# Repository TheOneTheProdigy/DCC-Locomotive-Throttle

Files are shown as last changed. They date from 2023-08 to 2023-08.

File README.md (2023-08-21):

# DCC-Locomotive-Throttle

The DCC-Locomotive-Throttle is a simple DIY, handheld controller that talks to a wThrottle Server (JMRI, DCC++EX and many others) using the wiThrottle protocol to control DCC model trains. 

---

## Prerequisites

1. Some basic soldering skills.  

    The components will work if just plugged together using jumpers, but they take a lot of space that way, so soldering them together is advised to make it hand held.

2. Loading the code (sketch) requires downloading of one of the IDEs, this sketch, the libraries, etc. so some experience with Arduinos is helpful, but not critical.

3. A wiThrottle Server to connect to. DCC-Locomotive-Throttle will work with any wiThrottle Server. e.g.

    * JMRI
    * DCC++EX
    * MRC WiFi
    * Dijitrax LnWi

---

## Building

Required Components

* ESP32 Lite Type C With Onboard Battery Circuit.
* 3x4 Keypad Matrix
* Polymer Lithium Ion Battery LiPo Maker Focus 2000mAh 3.7V JST Connector. On Battery BMS is a must for safety.
* KS0013  Rotary Encoder Module
* OLED Display 1.3" 128x64 I2C IIC SSD1306
* Case - 3D Printed
* Knob 3D Printed
* Wire - If you plan to solder the connections,which is the recommended approach, then stranded, coloured wire is advisable.
* Optional: Up to 7 additional buttons can be added, each with their own independent commands.

*Standard Configuration Pinouts*
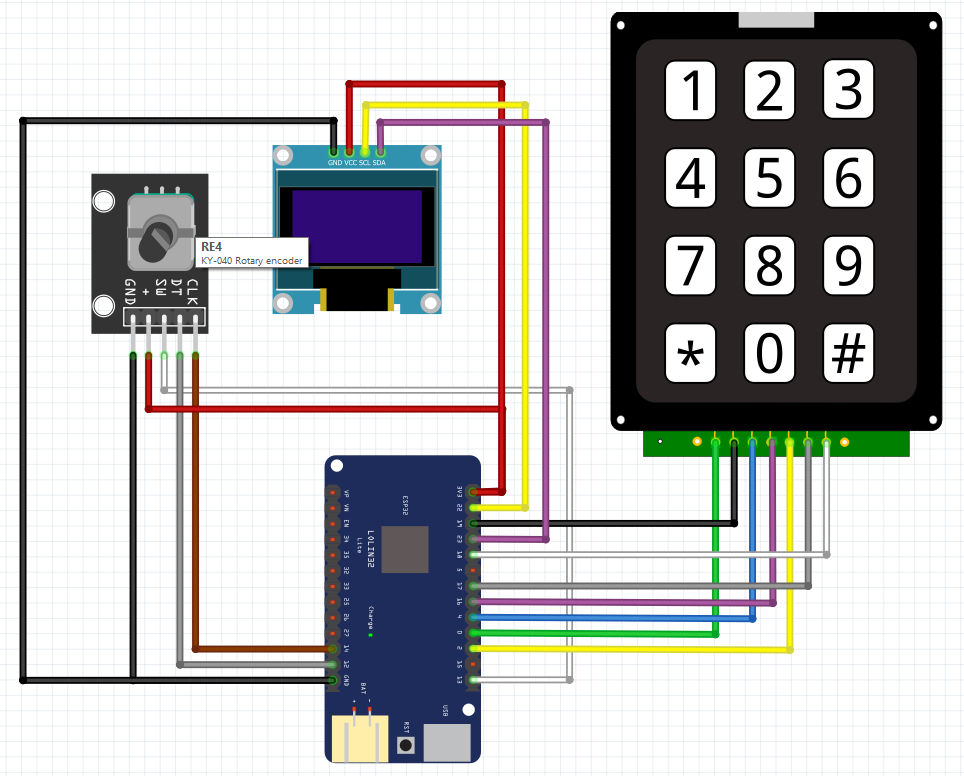
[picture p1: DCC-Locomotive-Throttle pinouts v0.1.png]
Assembly diagram


*Pinouts for Optional Additional Buttons*
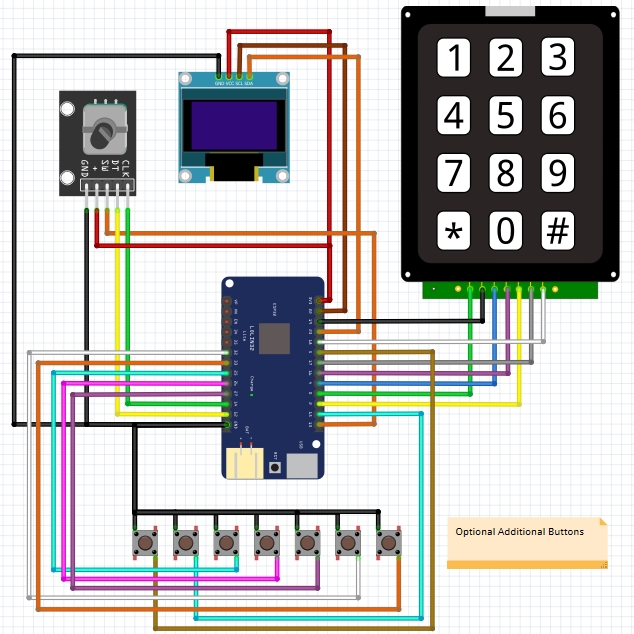
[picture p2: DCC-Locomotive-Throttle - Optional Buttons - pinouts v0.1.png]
Assembly diagram - Optional Additional Buttons


## Loading the code

1. Download the Arduino IDE.  
    * Available from  https://support.arduino.cc/hc/en-us/articles/360019833020-Download-and-install-Arduino-IDE
2. Download the esp32 boards in the Arduino IDE.
    * add the esp322 support with the following instructions:  (See here for detailed instructions:  https://randomnerdtutorials.com/installing-the-esp32-board-in-arduino-ide-windows-instructions/)
        * In the Arduino IDE, go to *File* > *Preferences*
        * Enter the following into the 'Additional Board Manager URLs' field:  https://dl.espressif.com/dl/package_esp32_index.json
    * Then Use the *Boards Manager* in the *Arduino IDE* to install the esp32 board support
        * *Tools* > *Board* > *Boards Manager*
        * Search for "esp32" by Expressive Systems.  Install version 1.0.6
3. Download or clone *this* repository. (Note: if you 'clone' initially, it is easier to receive updates to the code by doing a 'fetch' subsequently.  See Notes below.)
    * Clone - **First Time**
       * Install *GitHub Desktop* from https://desktop.github.com/
       * Create a free account on GitHub and authorise the app to allow it to connect top GitHub
       * Select *file* -> *Clone Repository* - or 'Clone an repository from the internet' from the welcome page then select the 'URL' tab
       * Enter *https://github.com/TheOneTheProdigy/DCC-Locomotive-Throttle* as the URL
       * Select a local folder to install it.  The default folder for the Arduino usually looks like "...username\Documents\Arduino\". (This is a good but not essential place to put it.)
       * Click *Clone*
       * **Subsequently**  (Anytime after the first 'clone')
         * click *Fetch Origin* and any changes to the code will be bought down to you PC, but you config_buttons.h and config_network.h will not be touched.
    * Download 
       * Open *https://github.com/TheOneTheProdigy/DCC-Locomotive-Throttle*
       * Click the green "Code" button and select download zip
       * Extract the zip file to a local folder.  The default folder for the Arduino usually looks like "...username\Documents\Arduino\". This is a good but not essential place to put it.
4. Load the needed libraries to your PC. These can loaded from the *Library Manager* in the *Arduino IDE*.
    * *U8g2lib.h* -  Search for "U8g2"   Install version 2.34.22
    * *AiEsp32RotaryEncoder.h* - search for "Ai Esp32 Rotary Encoder"  Install Version 1.6
    * *Keypad.h* - Search for "Keypad" by Mark Stanley   install version 3.1.1
    * *WiThrottleProtocol.h* - Search for "WiThrottleProtocol" (not "WiThrottle")  Install version 1.0.3 or later if available
5. These should have been automatically installed when you downloaded the esp32 boards.
    * *WiFi.h*  - https://github.com/espressif/arduino-esp32/tree/master/libraries/WiFi
    * *ESPmDNS.h* - https://github.com/espressif/arduino-esp32/blob/master/libraries/ESPmDNS
6. Copy '**config_network_example.h**' to a new file to '**config_network.h**'.
    * Then edit it to include the network ssids you want to use.  (Not essential, but entering passwords via the encoder is tedious.)
7. Copy '**config_buttons_example.h**' to a new file '**config_buttons.h**'.
    * Optionally, edit this to change the mapping of the keypad buttons to specific functions.
    * Optionally, edit this to configure the additional buttons (if you have included them) to specific functions.
    * Optionally, edit this to change if you want the function buttons to display when you press #, instead of the default of showing the Key Definitions
8. Upload the sketch.  
    * Select the board type as "WEMOS LOLIN32 Lite" in the *Arduino IDE*.
    * Connect the board via USB and select the appropriate port in the *Arduino IDE*.
    * Click *Upload* 

Notes: 
   * DCC-Locomotive-Throttle version 1.19 or later requires WiThrottleProtocol version 1.1.3 or later.
   * DCC-Locomotive-Throttle version 1.06 or later requires WiThrottleProtocol version 1.1.2 or later.
   * DCC-Locomotive-Throttle version 1.01 or later requires WiThrottleProtocol version 1.1.0 or later.
   * DCC-Locomotive-Throttle version 0.10 or later requires WiThrottleProtocol version 1.0.3 or later.
   * The *WiFi.h* and *ESPmDNS.h* libraries were automatically installed for me when I installed the esp32 boards, however you may need to install them manually.
   * Later versions of the esp board support are available and do appear to work, but if you have difficulties version 1.0.6 appears to be stable.
   * Later versions of the libraries generally should work, but if you have difficulties use the versions listed above.
   * To get the DCC-Locomotive-Throttle sketch I recommend using either the git command line, or the far more friendly 'GitHub Desktop' app.  See instructions above.
   * If you receive and error related to Python, and you are on MacOs 12 and above please edit the platform file, change from python to python3 as follows; preferences->user/path/arduino/packages/hardware/esp32/version/platform.txt and edit the line that looks as follows:tools.gen_esp32part.cmd=python3 "{runtime.platform.path}/tools/gen_esp32part.py"

---

## Using DCC-Locomotive-Throttle

**Currently functioning:**
- Provides a list of discovered SSIDs with the ability to choose one. When you select one:
  - if it is one in your specified list (in the sketch), it will use that specified password 
  - if it is a DCC++EX wiFi Command Station in access Point mode, it will guess the password
  - otherwise it will ask to enter the password (Use the rotary encoder to choose each character and the encoder button to select it.  * = backspace.  # = enter the password.) 
- Optionally provides a list of SSIDs with the specified passwords (in the sketch) to choose from
- Auto-connects to the first found wiThrottle Protocol Server if only one found, otherwise 
  - Asks which to connect to
  - If none found will ask to enter the IP Address and Port
  - Guesses the wiThrottle IP address and Port for DCC++EX WiFi Access Point mode Command Stations
  - optionally can add a #define (a preference) to disable this auto connect feature
- Rudimentary on-the-fly consists
- Assign commands directly to the 1-9 buttons (in the sketch) (see list below)
  - This is done in config_button.h
  - Latching / non-latching for the function is provided by the roster entry of wiThrottle server
- Optional ability to assign commands directly to the 1-7 additional buttons (in the sketch) (see list below)
  - These are defined config_button.h
- Command menu (see below for full list) including:
  - Able to select and deselect locos 
    - by their DCC address, via the keypad
      - On NCE systems, a leading zero (0) will force a long address
    - from the first 50 locos in the roster
  - Able to select multiple locos to create a consist
    - Able to change the facing of the additional locos in the consists (via the 'extra' menu after selection)
  - Able to activate any function (0-28)
    - Showing of the roster function labels (from the wiThrottle server if provided)
    - Quick access to the functions by pressing #. Temporarily enabled via the Extras menu (or permanently enabled in config_button.h)
    - Limited ability to configure which functions are sent to the first or all locos in a consist (defined in config_button.h)
  - Able to throw/close turnouts/points
    - from the address
    - from the first 50 turnouts/points in the server list
  - Able to activate routes
    - from their address
    - from the first 50 routes in the server list
  - Set/unset a multiplier for the rotary encoder
  - Power Track On/Off
  - Disconnect / Reconnect
  - Put ESP32 in deep sleep and restart it
- Have up to 6 throttles, each with an unlimited number of locos in consist. Default is 2 throttles, which can be increased or decreased temporarily via the Extras menu (or permanently enabled in config_button.h)
- Limited dealing with unexpected disconnects.  It will throw you back to the WiThtottle Server selection screen.
- Boundary between short and long DCC addresses can be configured in config_buttons.h
- The default speed step (per encoder click) can be configured in config_buttons.h
- The controller will automatically shut down if no SSID is selected or entered in 4 minutes (to conserve the battery)

**ToDo:**

### Command menu:
- 0-9 keys = pressing these directly will do whatever you has been preset in the sketch for them to do  (see \# below)
- \* = Menu:  The button press following the \* is the actual command:
  - 1 = Add loco.  
     - Followed by the loco number, followed by \# to complete.  e.g. to select loco 99 you would press '\*199\#'
     - or \# alone to show the roster   \# again will show the next page
  - 2 = Release loco:
     - Followed by the loco number, followed by \# to release an individual loco.  e.g. to deselect the loco 99 you would press '\*299\#'
     - Otherwise followed directly by \#  to release all e.g. '\*2\#'
  - 3 = Toggle direction.
  - 4 = Set / Unset a 3 or 6 times multiplier for the rotary encoder dial.
  - 5 = Set Route.    
      - Followed by the Route number, followed by \# to complete.  e.g. to Set route XX:XX:0012 '\*60012\#'  (where \'XX:XX:\' is a prefix defined in the sketch)
      - or \# alone to show the list from the server   \# again will show the next page
  - 6 = Throw turnout/point.  
     - Followed by the turnout/point number, followed by the \# to complete.  e.g. Throw turnout XX12 '\*512\#'  (where XX is a prefix defined in the sketch) 
     - or \# alone to show the list from the server   \# again will show the next page
  - 7 = Close turnout.    
     - Followed by the turnout/point number, followed by \# to complete.  e.g. Close turnout XX12 '\*612\#'  (where XX is a prefix defined in the sketch)
     - or \# alone to show the list from the server
  - 0 = Function button. Followed by...
      - the function number, Followed by \# to complete.  e.g. to set function 17 you would press '\*017\#'
      - \# alone, to show the list of functions.
  - 8 = Switch throttle to next locomotive / consist.
  - 9 = Extras. Followed by...
      - 0 then \# to toggle the action the the \# key does as a direct action, either to show the direct action key definitions, or the Function labels.  
      - 1 to change the facing of locos in a consist.
      - 2 Turn on/off track power.
      - 3 to toggle the heartbeat check.
      - 4 to increase the number of available throttle (up to 6)
      - 5 to decrease the number of available throttle (down to 1)
      - 6 then \# to Disconnect/Reconnect.  
      - 7 (or 9) then \# to put into deep sleep
Pressing '\*' again before the '\#' will terminate the current command (but not start a new command)
 - \# = Pressing # alone will show the function the the numbered keys (0-9) perform, outside the menu.
       Optionally, you can configure it so that the the Function labels from the roster show 

Pressing the Encoder button while the ESP32 is in Deep Sleep will revive it.

### Default number key assignments (0-9)  (outside the menu)

* 0 = FUNCTION_0 (DCC Lights)
* 1 = FUNCTION_1 (DCC Bell)
* 2 = FUNCTION_3 (DCC Horn/Whistle)
* 3 = FUNCTION_3
* 4 = FUNCTION_4
* 5 = FUNCTION_5
* 6 = FUNCTION_6 (DCC Brakes)
* 7 = FUNCTION_7
* 8 = FUNCTION_8
* 9 = FUNCTION_9

### Allowed assignments for the 0-9 keys:

Note: you need to edit config_buttons.h to alter these assignments   (copy config_buttons_example.h)
- FUNCTION_NULL   - don't do anything
- FUNCTION_0 - FUNCTION_28
- SPEED_STOP
- SPEED_UP
- SPEED_DOWN
- SPEED_UP_FAST
- SPEED_DOWN_FAST
- SPEED_MULTIPLIER
- E_STOP   - E Stop all locos on all throttles
- E_STOP_CURRENT_LOCO - E Stop locos on current throttle only
- POWER_TOGGLE
- POWER_ON
- POWER_OFF
- DIRECTION_TOGGLE
- DIRECTION_FORWARD
- DIRECTION_REVERSE
- NEXT_THROTTLE
- SPEED_STOP_THEN_TOGGLE_DIRECTION   - stops the loco if moving.  Toggles the direction if stationary.
- MAX_THROTTLE_INCREASE    - change the number of available throttles on-the-fly
- MAX_THROTTLE_DECREASE    - change the number of available throttles on-the-fly

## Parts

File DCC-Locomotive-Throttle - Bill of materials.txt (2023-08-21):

DCC Locomotive Throttle WiThrottle - Bill of material
 
Some of these items you will need to buy more than one unit or the cost will be higher.

USD$5 - ESP32 Lite Type C  (ESP32 Arduino with LiPo charger)
https://www.amazon.com/AITRIP-Bluetooth-Development-Antenna-MicroPython/dp/B0BCJXDYLY/

USD$5 - 3x4 Keypad
https://www.digikey.com/en/products/detail/sparkfun-electronics/COM-14662/8702491

USD$6 - Polymer Lithium Ion Battery LiPo 2000mAh 3.7V JST 1.25 Connector
https://www.makerfocus.com/products/makerfocus-3-7v-2000mah-lithium-rechargeable-battery-1s-3c-lipo-battery-with-protection-board-pack-of-4

USD$3 - KS0013  Rotary Encoder Module
https://www.microcenter.com/product/618904/inland-ks0013-keystudio-rotary-encoder-module

USD$8 - OLED Display 1.3" 128x64 Blue I2C 
https://www.microcenter.com/product/643965/inland-iic-spi-13-128x64-oled-v20-graphic-display-module-for-arduino-uno-r3

USD$.50 - JST 1.25 Mini Connector Female
https://www.amazon.com/JST1-25-Connector-1-25MM-Female-Cables/dp/B093WVXHSD/

USD$1 - 26AWG Silicone Wire Stranded Tinned Copper
https://www.amazon.com/Silicone-Electrical-electronics-stranded-Flexible/dp/B07TJZ9XRR/

USD$1 - 3D Printed Case and Brackets

USD$.25 - 3D Printed Knob

USD$29.75 - TOTAL Each Unit

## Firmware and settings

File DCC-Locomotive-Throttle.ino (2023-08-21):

/**
 Loco Throttle V1.28

 */

#include <WiFi.h>                 // https://github.com/espressif/arduino-esp32/tree/master/libraries/WiFi     
#include <ESPmDNS.h>              // https://github.com/espressif/arduino-esp32/blob/master/libraries/ESPmDNS 
#include <WiThrottleProtocol.h>   // https://github.com/TheOneTheProdigy/WiThrottleProtocol                             
#include <AiEsp32RotaryEncoder.h> // https://github.com/igorantolic/ai-esp32-rotary-encoder                    
#include <Keypad.h>               // https://www.arduinolibraries.info/libraries/keypad                     
#include <U8g2lib.h>              // https://github.com/olikraus/u8g2  
#include <string>

#include "config_network.h"      // LAN networks (SSIDs and passwords)
#include "config_buttons.h"      // keypad buttons assignments
#include "config_keypad_etc.h"   // hardware config - GPIOs - keypad, encoder; oled display type

#include "static.h"              // change for non-english languages
#include "actions.h"

#include "DCC-Locomotive-Throttle.h"

#if DCCLOCOMOTIVETHROTTLEDEBUG == 0
 #define debug_print(...) Serial.print(__VA_ARGS__)
 #define debug_println(...) Serial.print(__VA_ARGS__); Serial.print(" ("); Serial.print(millis()); Serial.println(")")
 #define debug_printf(...) Serial.printf(__VA_ARGS__)
#else
 #define debug_print(...)
 #define debug_println(...)
 #define debug_printf(...)
#endif

// *********************************************************************************

int keypadUseType = KEYPAD_USE_OPERATION;
int encoderUseType = ENCODER_USE_OPERATION;
int encoderButtonAction = ENCODER_BUTTON_ACTION;

boolean menuCommandStarted = false;
String menuCommand = "";
boolean menuIsShowing = false;

String oledText[18] = {"", "", "", "", "", "", "", "", "", "", "", "", "", "", "", "", "", ""};
bool oledTextInvert[18] = {false, false, false, false, false, false, false, false, false, 
                           false, false, false, false, false, false, false, false, false};

int currentSpeed[6];   // set to maximum possible (6)
Direction currentDirection[6];   // set to maximum possible (6)
int speedStepCurrentMultiplier = 1;

TrackPower trackPower = PowerUnknown;
String turnoutPrefix = "";
String routePrefix = "";

// encoder variables
bool circleValues = true;
int encoderValue = 0;
int lastEncoderValue = 0;

// server variables
// boolean ssidConnected = false;
String selectedSsid = "";
String selectedSsidPassword = "";
int ssidConnectionState = CONNECTION_STATE_DISCONNECTED;

// ssid password entry
String ssidPasswordEntered = "";
boolean ssidPasswordChanged = true;
char ssidPasswordCurrentChar = ssidPasswordBlankChar; 

IPAddress selectedWitServerIP;
int selectedWitServerPort = 0;
String selectedWitServerName ="";
int noOfWitServices = 0;
int witConnectionState = CONNECTION_STATE_DISCONNECTED;

//found wiThrottle servers
IPAddress foundWitServersIPs[maxFoundWitServers];
int foundWitServersPorts[maxFoundWitServers];
String foundWitServersNames[maxFoundWitServers];
int foundWitServersCount = 0;
bool autoConnectToFirstWiThrottleServer = AUTO_CONNECT_TO_FIRST_WITHROTTLE_SERVER;

//found ssids
String foundSsids[maxFoundSsids];
long foundSsidRssis[maxFoundSsids];
boolean foundSsidsOpen[maxFoundSsids];
int foundSsidsCount = 0;
int ssidSelectionSource;
double startWaitForSelection;

// wit Server ip entry
String witServerIpAndPortConstructed = "###.###.###.###:#####";
String witServerIpAndPortEntered = DEFAULT_IP_AND_PORT;
boolean witServerIpAndPortChanged = true;

// roster variables
int rosterSize = 0;
int rosterIndex[maxRoster]; 
String rosterName[maxRoster]; 
int rosterAddress[maxRoster];
char rosterLength[maxRoster];

int page = 0;
int functionPage = 0;

// turnout variables
int turnoutListSize = 0;
int turnoutListIndex[maxTurnoutList]; 
String turnoutListSysName[maxTurnoutList]; 
String turnoutListUserName[maxTurnoutList];
int turnoutListState[maxTurnoutList];

// route variables
int routeListSize = 0;
int routeListIndex[maxRouteList]; 
String routeListSysName[maxRouteList]; 
String routeListUserName[maxRouteList];
int routeListState[maxRouteList];

// function states
boolean functionStates[6][28];   // set to maximum possible (6 throttles)

// function labels
String functionLabels[6][28];   // set to maximum possible (6 throttles)

// consist function follow
int functionFollow[6][28];   // set to maximum possible (6 throttles)

// speedstep
int currentSpeedStep[6];   // set to maximum possible (6 throttles)

// throttle
int currentThrottleIndex = 0;
char currentThrottleIndexChar = '0';
int maxThrottles = MAX_THROTTLES;

int heartBeatPeriod = 10; // default to 10 seconds
long lastServerResponseTime;  // seconds since start of Arduino
boolean heartbeatCheckEnabled = true;

// used to stop speed bounces
long lastSpeedSentTime = 0;
int lastSpeedSent = 0;
// int lastDirectionSent = -1;
int lastSpeedThrottleIndex = 0;

// don't alter the assignments here
// alter them in config_buttons.h

const char* deviceName = DEVICE_NAME;

const boolean encoderRotationClockwiseIsIncreaseSpeed = ENCODER_ROTATION_CLOCKWISE_IS_INCREASE_SPEED;
// false = Counterclockwise  true = clockwise

const boolean toggleDirectionOnEncoderButtonPressWhenStationary = TOGGLE_DIRECTION_ON_ENCODER_BUTTON_PRESSED_WHEN_STATIONARY;
// true = if the locos(s) are stationary, clicking the encoder button will toggle the direction

//4x3 keypad
int buttonActions[10] = { CHOSEN_KEYPAD_0_FUNCTION,
                          CHOSEN_KEYPAD_1_FUNCTION,
                          CHOSEN_KEYPAD_2_FUNCTION,
                          CHOSEN_KEYPAD_3_FUNCTION,
                          CHOSEN_KEYPAD_4_FUNCTION,
                          CHOSEN_KEYPAD_5_FUNCTION,
                          CHOSEN_KEYPAD_6_FUNCTION,
                          CHOSEN_KEYPAD_7_FUNCTION,
                          CHOSEN_KEYPAD_8_FUNCTION,
                          CHOSEN_KEYPAD_9_FUNCTION
};

// text that will appear when you press #
const String directCommandText[4][3] = {
    {CHOSEN_KEYPAD_1_DISPLAY_NAME, CHOSEN_KEYPAD_2_DISPLAY_NAME, CHOSEN_KEYPAD_3_DISPLAY_NAME},
    {CHOSEN_KEYPAD_4_DISPLAY_NAME, CHOSEN_KEYPAD_5_DISPLAY_NAME, CHOSEN_KEYPAD_6_DISPLAY_NAME},
    {CHOSEN_KEYPAD_7_DISPLAY_NAME, CHOSEN_KEYPAD_8_DISPLAY_NAME, CHOSEN_KEYPAD_9_DISPLAY_NAME},
    {"* Menu", CHOSEN_KEYPAD_0_DISPLAY_NAME, "# This"}
};

bool oledDirectCommandsAreBeingDisplayed = false;
#ifdef HASH_SHOWS_FUNCTIONS_INSTEAD_OF_KEY_DEFS
  boolean hashShowsFunctionsInsteadOfKeyDefs = HASH_SHOWS_FUNCTIONS_INSTEAD_OF_KEY_DEFS;
#else
  boolean hashShowsFunctionsInsteadOfKeyDefs = false;
#endif

// in case the values are not defined in config_buttons.h
// DO NOT alter the values here 
#ifndef CHOSEN_ADDITIONAL_BUTTON_0_FUNCTION
  #define CHOSEN_ADDITIONAL_BUTTON_0_FUNCTION FUNCTION_NULL
#endif
#ifndef CHOSEN_ADDITIONAL_BUTTON_1_FUNCTION
  #define CHOSEN_ADDITIONAL_BUTTON_1_FUNCTION FUNCTION_NULL
#endif
#ifndef CHOSEN_ADDITIONAL_BUTTON_2_FUNCTION
  #define CHOSEN_ADDITIONAL_BUTTON_2_FUNCTION FUNCTION_NULL
#endif
#ifndef CHOSEN_ADDITIONAL_BUTTON_3_FUNCTION
  #define CHOSEN_ADDITIONAL_BUTTON_3_FUNCTION FUNCTION_NULL
#endif
#ifndef CHOSEN_ADDITIONAL_BUTTON_4_FUNCTION
  #define CHOSEN_ADDITIONAL_BUTTON_4_FUNCTION FUNCTION_NULL
#endif
#ifndef CHOSEN_ADDITIONAL_BUTTON_5_FUNCTION
  #define CHOSEN_ADDITIONAL_BUTTON_5_FUNCTION FUNCTION_NULL
#endif
#ifndef CHOSEN_ADDITIONAL_BUTTON_6_FUNCTION
  #define CHOSEN_ADDITIONAL_BUTTON_6_FUNCTION FUNCTION_NULL
#endif

//optional additional buttons
int additionalButtonActions[MAX_ADDITIONAL_BUTTONS] = {
                          CHOSEN_ADDITIONAL_BUTTON_0_FUNCTION,
                          CHOSEN_ADDITIONAL_BUTTON_1_FUNCTION,
                          CHOSEN_ADDITIONAL_BUTTON_2_FUNCTION,
                          CHOSEN_ADDITIONAL_BUTTON_3_FUNCTION,
                          CHOSEN_ADDITIONAL_BUTTON_4_FUNCTION,
                          CHOSEN_ADDITIONAL_BUTTON_5_FUNCTION,
                          CHOSEN_ADDITIONAL_BUTTON_6_FUNCTION
};
unsigned long lastAdditionalButtonDebounceTime[MAX_ADDITIONAL_BUTTONS] = {0,0,0,0,0,0,0};  // the last time the output pin was toggled
unsigned long additionalButtonDebounceDelay = ADDITIONAL_BUTTON_DEBOUNCE_DELAY;    // the debounce time


// *********************************************************************************

void displayUpdateFromWit(int multiThrottleIndex) {
  debug_print("displayUpdateFromWit(): keyapdeUseType "); debug_print(keypadUseType); 
  debug_print(" menuIsShowing "); debug_print(menuIsShowing);
  debug_print(" multiThrottleIndex "); debug_print(multiThrottleIndex);
  debug_println("");
  if ( (keypadUseType==KEYPAD_USE_OPERATION) && (!menuIsShowing) 
  && (multiThrottleIndex==currentThrottleIndex) ) {
    writeOledSpeed();
  }
}

// WiThrottleProtocol Delegate class
class MyDelegate : public WiThrottleProtocolDelegate {
  
  public:
    void heartbeatConfig(int seconds) { 
      debug_print("Received heartbeat. From: "); debug_print(heartBeatPeriod); 
      debug_print(" To: "); debug_println(seconds); 
      heartBeatPeriod = seconds;
    }
    void receivedVersion(String version) {    
      debug_printf("Received Version: %s\n",version); 
    }
    void receivedServerDescription(String description) {
      debug_print("Received Description: "); debug_println(description);
      if (description.substring(0,6).equals("DCC-EX")) {
        debug_println("resetting prefixes");
        turnoutPrefix = DCC_EX_TURNOUT_PREFIX;
        routePrefix = DCC_EX_ROUTE_PREFIX;
      }
    }
    void receivedSpeedMultiThrottle(char multiThrottle, int speed) {             // Vnnn
      debug_print("Received Speed: ("); debug_print(millis()); debug_print(") speed: "); debug_println(speed); 
      int multiThrottleIndex = getMultiThrottleIndex(multiThrottle);

      if (currentSpeed[multiThrottleIndex] != speed) {
        
        // check for bounce. (intermediate speed sent back from the server, but is not up to date with the throttle)
        if ( (lastSpeedThrottleIndex!=multiThrottleIndex)
             || ((millis()-lastSpeedSentTime)>500)
        ) {
          currentSpeed[multiThrottleIndex] = speed;
          displayUpdateFromWit(multiThrottleIndex);
        } else {
          debug_print("Received Speed: skipping response: ("); debug_print(millis()); debug_print(") speed: "); debug_println(speed);
        }
      }
    }
    void receivedDirectionMultiThrottle(char multiThrottle, Direction dir) {     // R{0,1}
      debug_print("Received Direction: "); debug_println(dir); 
      int multiThrottleIndex = getMultiThrottleIndex(multiThrottle);

      if (currentDirection[multiThrottleIndex] != dir) {
        currentDirection[multiThrottleIndex] = dir;
        displayUpdateFromWit(multiThrottleIndex);
      }
    }
    void receivedFunctionStateMultiThrottle(char multiThrottle, uint8_t func, bool state) { 
      debug_print("Received Fn: "); debug_print(func); debug_print(" State: "); debug_println( (state) ? "True" : "False" );
      int multiThrottleIndex = getMultiThrottleIndex(multiThrottle);

      if (functionStates[multiThrottleIndex][func] != state) {
        functionStates[multiThrottleIndex][func] = state;
        displayUpdateFromWit(multiThrottleIndex);
      }
    }
    void receivedRosterFunctionListMultiThrottle(char multiThrottle, String functions[28]) { 
      debug_println("Received Fn List: "); 
      int multiThrottleIndex = getMultiThrottleIndex(multiThrottle);
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
void loop() {
  
  if (ssidConnectionState != CONNECTION_STATE_CONNECTED) {
    // connectNetwork();
    ssidsLoop();
    checkForShutdownOnNoResponse();
  } else {  
    if (witConnectionState != CONNECTION_STATE_CONNECTED) {
      witServiceLoop();
    } else {
      wiThrottleProtocol.check();    // parse incoming messages

      setLastServerResponseTime(false);

      if ( (lastServerResponseTime+(heartBeatPeriod*4) < millis()/1000) 
      && (heartbeatCheckEnabled) ) {
        debug_print("Disconnected - Last:");  debug_print(lastServerResponseTime); debug_print(" Current:");  debug_println(millis()/1000);
        reconnect();
      }
    }
  }
  char key = keypad.getKey();
  rotary_loop();

  additionalButtonLoop(); 

	// debug_println("loop:" );
}

// *********************************************************************************
//  Key press and Menu
// *********************************************************************************

void doKeyPress(char key, boolean pressed) {
  debug_print("doKeyPress(): "); 

  if (pressed)  { //pressed
    switch (keypadUseType) {
      case KEYPAD_USE_OPERATION:
        debug_print("key operation... "); debug_println(key);
        switch (key) {
          case '*':  // menu command
            menuCommand = "";
            if (menuCommandStarted) { // then cancel the menu
              resetMenu();
              writeOledSpeed();
            } else {
              menuCommandStarted = true;
              debug_println("Command started");
              writeOledMenu("");
            }
            break;

          case '#': // end of command
            debug_print("end of command... "); debug_print(key); debug_print ("  :  "); debug_println(menuCommand);
            if ((menuCommandStarted) && (menuCommand.length()>=1)) {
              doMenu();
            } else {
              if (!hashShowsFunctionsInsteadOfKeyDefs) {
                if (!oledDirectCommandsAreBeingDisplayed) {
                  writeOledDirectCommands();
                } else {
                  oledDirectCommandsAreBeingDisplayed = false;
                  writeOledSpeed();
                }
              } else {
                writeOledFunctionList(""); 
              }
            }
            break;

          case '0': case '1': case '2': case '3': case '4': 
          case '5': case '6': case '7': case '8': case '9':
            debug_print("number... "); debug_print(key); debug_print ("  cmd: '"); debug_print(menuCommand); debug_println("'");

            if (menuCommandStarted) { // append to the string

              if ((menuCharsRequired[key-48] == 0) && (menuCommand.length() == 0)) { // menu type is effectively a direct commands from this point
                menuCommand += key;
                doMenu();
              } else {
                if ((menuCharsRequired[menuCommand.substring(0,1).toInt()] == 1) && (menuCommand.length() == 1)) {  // menu type needs only one char
                  menuCommand += key;
                  doMenu();

                } else {  //menu type allows/requires more than one char
                  menuCommand += key;
                  writeOledMenu(menuCommand);
                }
              }
            } else {
              doDirectCommand(key, true);
            }
            break;

          default:  //A, B, C, D
            doDirectCommand(key, true);
            break;
        }
        break;

      case KEYPAD_USE_ENTER_WITHROTTLE_SERVER:
        debug_print("key: Enter wit... "); debug_println(key);
        switch (key){
          case '0': case '1': case '2': case '3': case '4': 
          case '5': case '6': case '7': case '8': case '9':
            witEntryAddChar(key);
            break;
          case '*': // backspace
            witEntryDeleteChar(key);
            break;
          case '#': // end of command
            if (witServerIpAndPortEntered.length() == 17) {
              witConnectionState = CONNECTION_STATE_ENTERED;
            }
            break;
          default:  // do nothing 
            break;
        }

        break;

      case KEYPAD_USE_ENTER_SSID_PASSWORD:
        debug_print("key: Enter password... "); debug_println(key);
        switch (key){
          case '0': case '1': case '2': case '3': case '4': 
          case '5': case '6': case '7': case '8': case '9':
            ssidPasswordAddChar(key);
            break;
          case '*': // backspace
            ssidPasswordDeleteChar(key);
            break;
          case '#': // end of command
              selectedSsidPassword = ssidPasswordEntered;
              encoderUseType = ENCODER_USE_OPERATION;
              keypadUseType = KEYPAD_USE_OPERATION;
              ssidConnectionState = CONNECTION_STATE_SELECTED;
            break;
          default:  // do nothing 
            break;
        }

        break;

      case KEYPAD_USE_SELECT_WITHROTTLE_SERVER:
        debug_print("key: Select wit... "); debug_println(key);
        switch (key){
          case '0': case '1': case '2': case '3': case '4':
            selectWitServer(key - '0');
            break;
          case '#': // show ip address entry screen
            witConnectionState = CONNECTION_STATE_ENTRY_REQUIRED;
            buildWitEntry();
            enterWitServer();
            break;
          default:  // do nothing 
            break;
        }
        break;

      case KEYPAD_USE_SELECT_SSID:
        debug_print("key ssid... "); debug_println(key);
        switch (key){
          case '0': case '1': case '2': case '3': case '4': 
          case '5': case '6': case '7': case '8': case '9':
            selectSsid(key - '0');
            break;
          case '#': // show found SSIds
            ssidConnectionState = CONNECTION_STATE_DISCONNECTED;
            keypadUseType = KEYPAD_USE_SELECT_SSID_FROM_FOUND;
            ssidSelectionSource = SSID_CONNECTION_SOURCE_BROWSE;
            // browseSsids();
            break;
          default:  // do nothing 
            break;
        }
        break;

      case KEYPAD_USE_SELECT_SSID_FROM_FOUND:
        debug_print("key ssid from found... "); debug_println(key);
        switch (key){
          case '0': case '1': case '2': case '3': case '4': 
            selectSsidFromFound(key - '0'+(page*5));
            break;
          case '#': // next page
            if (foundSsidsCount>5) {
              if ( (page+1)*5 < foundSsidsCount ) {
                page++;
              } else {
                page = 0;
              }
              writeOledFoundSSids(""); 
            }
            break;
          case '9': // show in code list of SSIDs
            ssidConnectionState = CONNECTION_STATE_DISCONNECTED;
            keypadUseType = KEYPAD_USE_SELECT_SSID;
            ssidSelectionSource = SSID_CONNECTION_SOURCE_LIST;
            break;
          default:  // do nothing 
            break;
        }
        break;

      case KEYPAD_USE_SELECT_ROSTER:
        debug_print("key Roster... "); debug_println(key);
        switch (key){
          case '0': case '1': case '2': case '3': case '4': 
          case '5': case '6': case '7': case '8': case '9':
            selectRoster((key - '0')+(page*5));
            break;
          case '#':  // next page
            if ( rosterSize > 5 ) {
              if ( (page+1)*5 < rosterSize ) {
                page++;
              } else {
                page = 0;
              }
              writeOledRoster(""); 
            }
            break;
          case '*':  // cancel
            resetMenu();
            writeOledSpeed();
            break;
          default:  // do nothing 
            break;
        }
        break;

      case KEYPAD_USE_SELECT_TURNOUTS_THROW:
      case KEYPAD_USE_SELECT_TURNOUTS_CLOSE:
        debug_print("key turnouts... "); debug_println(key);
        switch (key){
          case '0': case '1': case '2': case '3': case '4': 
          case '5': case '6': case '7': case '8': case '9':
            selectTurnoutList((key - '0')+(page*10), (keypadUseType == KEYPAD_USE_SELECT_TURNOUTS_THROW) ? TurnoutThrow : TurnoutClose);
            break;
          case '#':  // next page
            if ( turnoutListSize > 10 ) {
              if ( (page+1)*10 < turnoutListSize ) {
                page++;
              } else {
                page = 0;
              }
              writeOledTurnoutList("", (keypadUseType == KEYPAD_USE_SELECT_TURNOUTS_THROW) ? TurnoutThrow : TurnoutClose); 
            }
            break;
          case '*':  // cancel
            resetMenu();
            writeOledSpeed();
            break;
          default:  // do nothing 
            break;
        }
        break;
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

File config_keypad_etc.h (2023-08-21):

///Keypad + encoder + oLed config

// *******************************************************************************************************************
// encoder

// large EPS32
// #define ROTARY_ENCODER_A_PIN 33
// #define ROTARY_ENCODER_B_PIN 32
// #define ROTARY_ENCODER_BUTTON_PIN 27

// Small ESP32
#define ROTARY_ENCODER_A_PIN 12
#define ROTARY_ENCODER_B_PIN 14
#define ROTARY_ENCODER_BUTTON_PIN 13

#define ROTARY_ENCODER_VCC_PIN -1 /* 27 put -1 of Rotary encoder Vcc is connected directly to 3,3V; else you can use declared output pin for powering rotary encoder */
#define ROTARY_ENCODER_STEPS 2 //depending on your encoder - try 1,2 or 4 to get expected behaviour

const int encoderDebounceTime = 5;   // in miliseconds

// *******************************************************************************************************************
// keypad

// 4x4 keypad
// #define ROW_NUM     4 // four rows
// #define COLUMN_NUM  4 // four columns
// char keys[ROW_NUM][COLUMN_NUM] = {
//   {'1', '2', '3', 'A'},
//   {'4', '5', '6', 'B'},
//   {'7', '8', '9', 'C'},
//   {'*', '0', '#', 'D'}
// };
// byte pin_rows[ROW_NUM]      = {19, 18, 5, 17}; // connect to the row pins
// byte pin_column[COLUMN_NUM] = {16, 4, 2, 15};   // connect to the column pins

// 4x3 keypad
#define ROW_NUM     4 // four rows
#define COLUMN_NUM  3 // four columns
char keys[ROW_NUM][COLUMN_NUM] = {
 {'1', '2', '3'},
 {'4', '5', '6'},
 {'7', '8', '9'},
 {'*', '0', '#'}
};
byte pin_rows[ROW_NUM]      = {19, 18, 17, 16}; // GIOP19, GIOP18, GIOP5, GIOP17 connect to the row pins
byte pin_column[COLUMN_NUM] = { 4, 0, 2};   // GIOP16, GIOP4, GIOP0 connect to the column pins

Keypad keypad = Keypad( makeKeymap(keys), pin_rows, pin_column, ROW_NUM, COLUMN_NUM );
const int keypadDebounceTime = 10;   // in miliseconds
const int keypadHoldTime = 200;   // in miliseconds

// consists follow functions
#ifndef CONSIST_FUNCTION_FOLLOW_F0
    #define CONSIST_FUNCTION_FOLLOW_F0                  CONSIST_ALL_LOCOS            // lights
#endif
#ifndef CONSIST_FUNCTION_FOLLOW_F1
    #define CONSIST_FUNCTION_FOLLOW_F1                  CONSIST_LEAD_LOCO            // bell
#endif
#ifndef CONSIST_FUNCTION_FOLLOW_F2
    #define CONSIST_FUNCTION_FOLLOW_F2                  CONSIST_LEAD_LOCO            // horn
#endif
#ifndef CONSIST_FUNCTION_FOLLOW_F6
    #define CONSIST_FUNCTION_FOLLOW_F6                  CONSIST_ALL_LOCOS            // brakes
#endif
#ifndef CONSIST_FUNCTION_FOLLOW_OTHER_FUNCTIONS
    #define CONSIST_FUNCTION_FOLLOW_OTHER_FUNCTIONS     CONSIST_LEAD_LOCO
#endif

// *******************************************************************************************************************
// additional / optional buttons

// To use the additional buttons, adjust the functions assigned to them in config_buttons.h
#define MAX_ADDITIONAL_BUTTONS 7  // If you alter this number, you must also alter the additionalButtonActions array in DCC-Locomotive-Throttle.ino
int additionalButtonPin[MAX_ADDITIONAL_BUTTONS] = {5,15,25,26,27,32,33};
int additionalButtonType[MAX_ADDITIONAL_BUTTONS] = {INPUT_PULLUP,INPUT_PULLUP,INPUT_PULLUP,INPUT_PULLUP,INPUT_PULLUP,INPUT_PULLUP,INPUT_PULLUP};   // 34,35,36,39 don't have an internal pullup
boolean additionalButtonRead[MAX_ADDITIONAL_BUTTONS] =     {0,0,0,0,0,0,0};
boolean additionalButtonLastRead[MAX_ADDITIONAL_BUTTONS] = {0,0,0,0,0,0,0};

#ifndef ADDITIONAL_BUTTON_DEBOUNCE_DELAY
    #define ADDITIONAL_BUTTON_DEBOUNCE_DELAY 50   // default if not defined in config_buttons.h
#endif

// *******************************************************************************************************************
// other options
#ifndef HASH_SHOWS_FUNCTIONS_INSTEAD_OF_KEY_DEFS
    #define HASH_SHOWS_FUNCTIONS_INSTEAD_OF_KEY_DEFS false  // default if not defined in config_buttons.h
#endif

#ifndef MAX_THROTTLES
    #define MAX_THROTTLES 2  // default if not defined in config_buttons.h
#endif

#ifndef ENCODER_BUTTON_ACTION
    #define ENCODER_BUTTON_ACTION SPEED_STOP_THEN_TOGGLE_DIRECTION  // default if not defined in config_buttons.h
#endif

// *******************************************************************************************************************
// OLED

#ifdef U8X8_HAVE_HW_SPI
    #include <SPI.h>                       // add to include path [Arduino install]\hardware\arduino\avr\libraries\SPI\src
#endif
#ifdef U8X8_HAVE_HW_I2C
    #include <Wire.h>                      // add to include path [Arduino install]\hardware\arduino\avr\libraries\Wire\src
#endif

// U8g2 Constructor List (Frame Buffer)
// you can overide this in config_buttons.h     DO NOT CHANGE IT HERE
#ifndef OLED_TYPE
    U8G2_SSD1306_128X64_NONAME_F_HW_I2C u8g2(U8G2_R0, /* reset=*/ U8X8_PIN_NONE, /* clock=*/ 22, /* data=*/ 23);
#else
    OLED_TYPE
#endif

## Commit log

2023-08-10 Update Branding
    [DCCTrainThrottle - optional buttons v0.1.fzz, DCCTrainThrottle v0.1.fzz]
2023-08-21 Update Default Buttons
    [config_buttons_keep.txt]
2023-08-21 Change Names
    [DCCLocoThrottle - optional buttons v0.1.fzz, DCCLocoThrottle v0.1.fzz, DCCTrainThrottle - optional buttons v0.1.fzz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]
2023-08-21 Cleanup Folders
    [DCC-Loco-Throttle - optional buttons v0.1.fzz, DCC-Loco-Throttle v0.1.fzz, DCCLocoThrottle - optional buttons v0.1.fzz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]
2023-08-21 Fix Arduino IDE Folders
    [DCC-Loco-Throttle - optional buttons v0.1.fzz, DCC-Loco-Throttle v0.1.fzz, DCC-Locomotive-Throttle - optional buttons v0.1.fzz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]
2023-08-21 Fix Compile Errors and Repository
    [DCC-Locomotive-Throttle.ino, static.h]
2023-08-21 Fix Brakes On F6 All Locos
    [config_keypad_etc.h]
2023-08-21 Update BOM For USA Vendors
